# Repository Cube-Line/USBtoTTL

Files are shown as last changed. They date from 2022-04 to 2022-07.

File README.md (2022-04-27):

# USB转串口小工具硬件
发现大多数TB的USB串口工具老出各种意外,于是自己画了一版.
* 主控芯片使用CP2104,通讯速率最大可达2Mbps.
* 集成了功率开关-BD2243G-GTR(限流500mA)
* 集成电源和过功率指示灯、接收发送指示灯.
* USB口添加ESD保护-BDFN1710A054U.
* 添加3.3V线性稳压器，支持3V3逻辑电平.
* 添加DTR流控制，支持Arduino自动下载.

## 仿真图
* TOP  
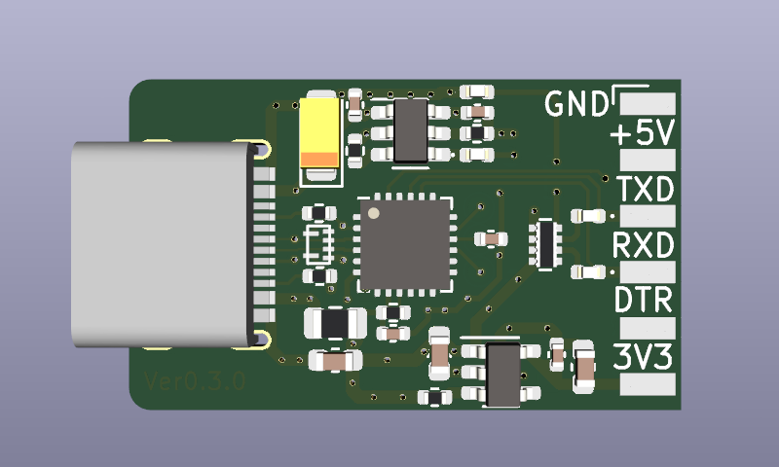
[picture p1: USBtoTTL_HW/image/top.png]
TOP
  
* BOTTOM  
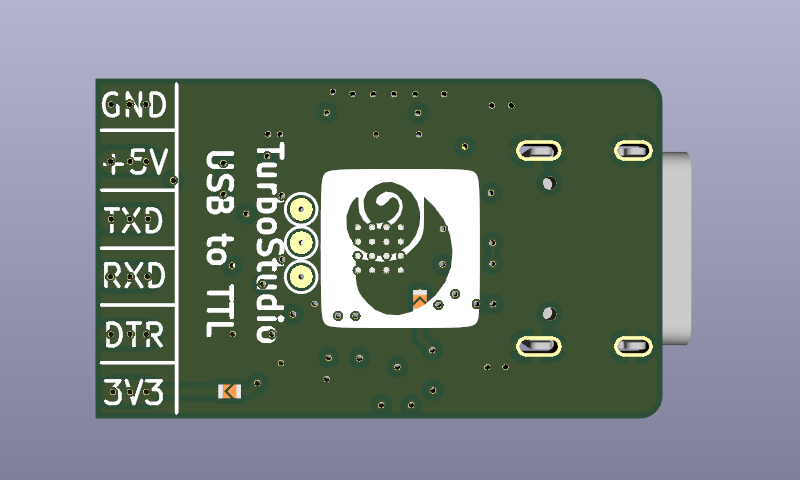
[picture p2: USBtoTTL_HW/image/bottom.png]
BOTTOM


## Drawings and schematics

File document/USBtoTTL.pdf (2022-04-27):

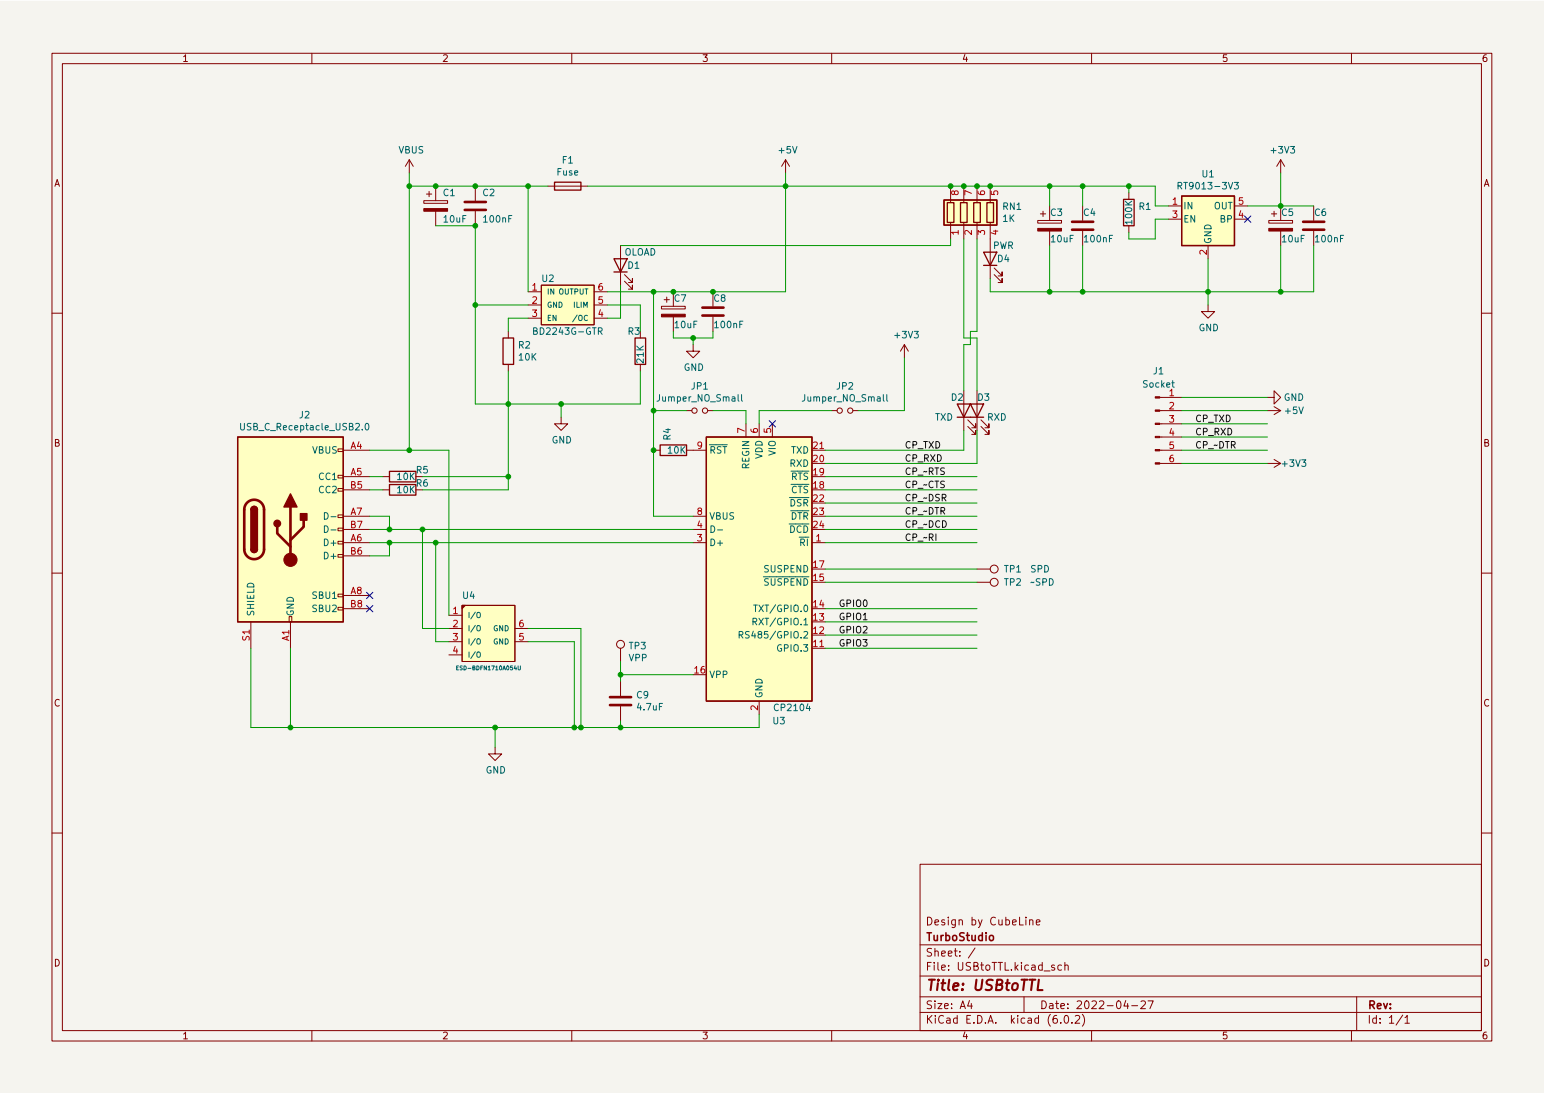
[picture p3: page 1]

2 RXD 20 TXD 21 ~{DSR}22 ~{DTR}23 ~{DCD}24 D+ 3 D- 4 VIO

File: USBtoTTL.kicad_sch Sheet: / TurboStudio Design by CubeLine

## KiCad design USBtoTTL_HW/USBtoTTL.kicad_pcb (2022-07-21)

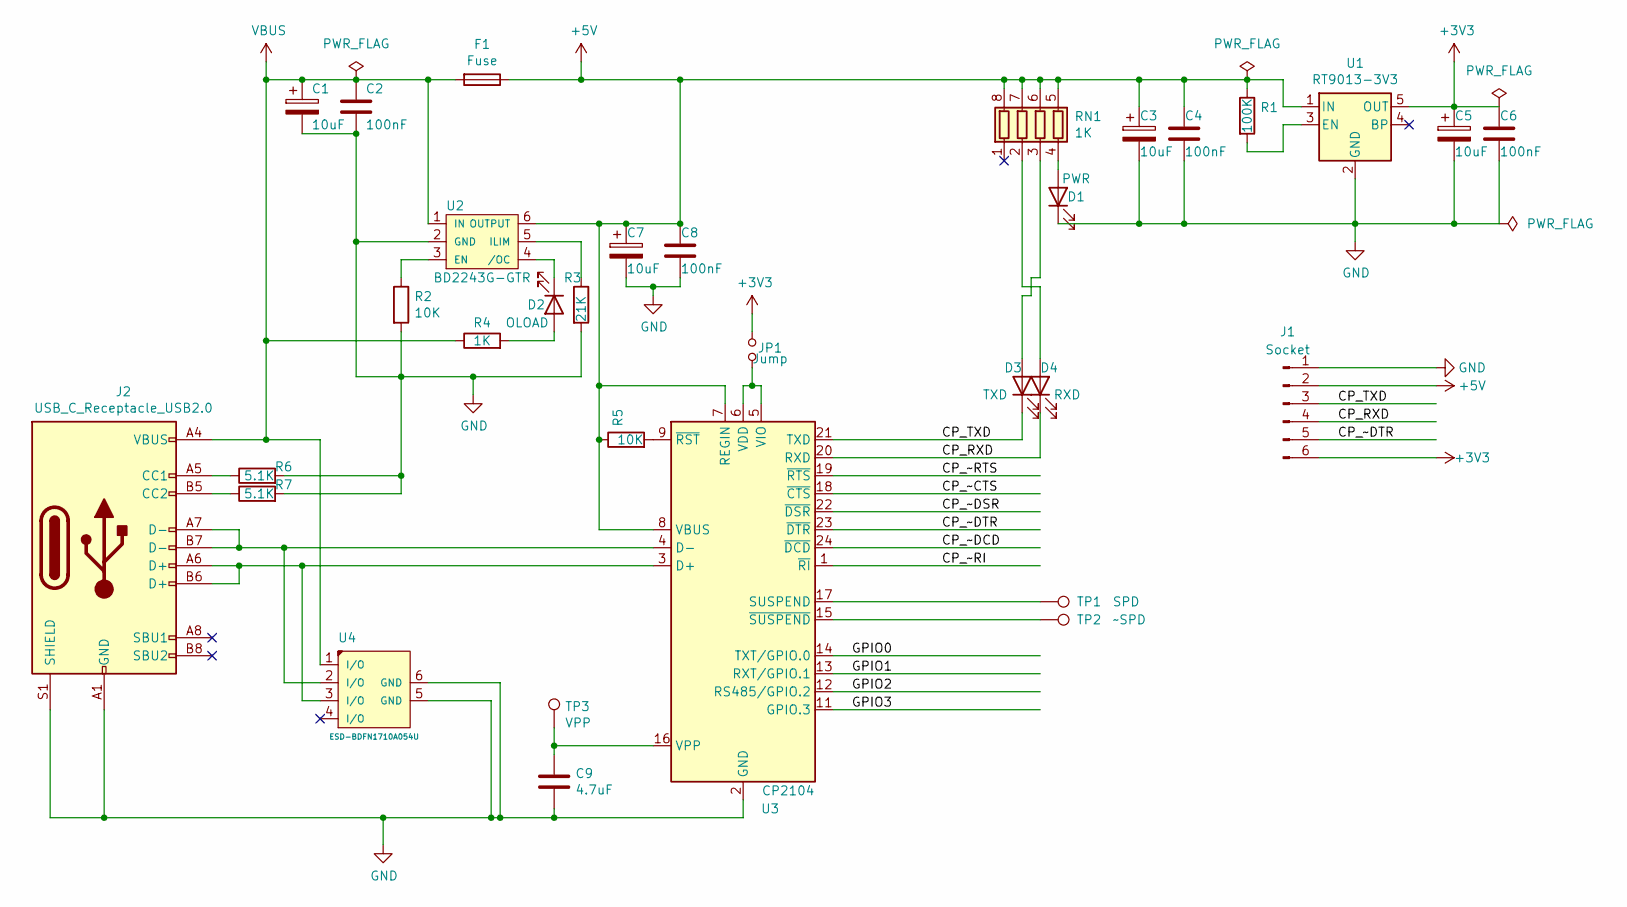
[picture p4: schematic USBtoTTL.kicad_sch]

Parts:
C1: 10uF; CP_EIA-3216-10_Kemet-I
C2, C4, C6, C8: 100nF; C_0402_1005Metric
C3, C5, C7: 10uF; C_0603_1608Metric
C9: 4.7uF; C_0402_1005Metric
D1: PWR; LED_0402_1005Metric
D2: OLOAD; LED_0402_1005Metric
D3: TXD; LED_0402_1005Metric
D4: RXD; LED_0402_1005Metric
F1: Fuse; Fuse_0805_2012Metric
J1: Socket; Harwin_M20-89006xx_1x06_P2.54mm_Horizontal
J2: USB_C_Receptacle_USB2.0; USB_C_Receptacle_HRO_TYPE-C-31-M-12
JP1: Jump; JUMP_OPEN_2P_0.3MMx0.5MM
R1: 100K; R_0402_1005Metric
R2, R5: 10K; R_0402_1005Metric
R3: 21K; R_0402_1005Metric
R4: 1K; R_0402_1005Metric
R6, R7: 5.1K; R_0402_1005Metric
RN1: 1K; R_Array_Concave_4x0402
TP1: SPD; TestPoint_Pad_D1.0mm
TP2: ~SPD; TestPoint_Pad_D1.0mm
TP3: VPP; TestPoint_Pad_D1.0mm
U1: RT9013-3V3; SOT-23-5
U2: BD2243G-GTR; SOT-23-6
U3: CP2104; QFN-24-1EP_4x4mm_P0.5mm_EP2.6x2.6mm
U4: ESD-BDFN1710A054U; DFN1710-6

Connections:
+3V3: C5.1, C6.1, J1.6, JP1.2, U1.5 (OUT)
+5V: C3.1, C4.1, C7.1, C8.1, F1.1, J1.2, R1.1, R5.1, RN1.5 (R4.2), RN1.6 (R3.2), RN1.7 (R2.2), RN1.8 (R1.2), U1.1 (IN), U2.6 (OUTPUT), U3.7 (REGIN), U3.8 (VBUS)
/CP_RXD: D4.1 (K), J1.4, U3.20 (RXD)
/CP_TXD: D3.1 (K), J1.3, U3.21 (TXD)
/CP_~CTS: U3.18 (~CTS)
/CP_~DCD: U3.24 (~DCD)
/CP_~DSR: U3.22 (~DSR)
/CP_~DTR: J1.5, U3.23 (~DTR)
/CP_~RI: U3.1 (~RI)
/CP_~RTS: U3.19 (~RTS)
/GPIO0: U3.14 (TXT/GPIO.0)
/GPIO1: U3.13 (RXT/GPIO.1)
/GPIO2: U3.12 (RS485/GPIO.2)
/GPIO3: U3.11 (GPIO.3)
GND: C1.2, C2.2, C3.2, C4.2, C5.2, C6.2, C7.2, C8.2, C9.2, D1.1 (K), J1.1, J2.A1 (GND), J2.A12 (GND), J2.B1 (GND), J2.B12 (GND), J2.S1 (SHIELD), R2.2, R3.2, R6.2, R7.2, U1.2 (GND), U2.2 (GND), U3.2 (GND), U3.25 (GND), U4.5 (GND), U4.6 (GND)
unnamed: C9.1, TP3.1, U3.16 (VPP)
unnamed: D1.2 (A), RN1.4 (R4.1)
unnamed: D2.1 (K), U2.4 (/OC)
unnamed: D2.2 (A), R4.2
unnamed: D3.2 (A), RN1.3 (R3.1)
unnamed: D4.2 (A), RN1.2 (R2.1)
unnamed: J2.A5 (CC1), R6.1
unnamed: J2.A6 (D+), J2.B6 (D+), U3.3 (D+), U4.3 (I/O)
unnamed: J2.A7 (D-), J2.B7 (D-), U3.4 (D-), U4.2 (I/O)
unnamed: J2.B5 (CC2), R7.1
unnamed: JP1.1, U3.5 (VIO), U3.6 (VDD)
unnamed: R1.2, U1.3 (EN)
unnamed: R2.1, U2.3 (EN)
unnamed: R3.1, U2.5 (ILIM)
unnamed: R5.2, U3.9 (~RST)
unnamed: TP1.1, U3.17 (SUSPEND)
unnamed: TP2.1, U3.15 (~SUSPEND)
VBUS: C1.1, C2.1, F1.2, J2.A4 (VBUS), J2.A9 (VBUS), J2.B4 (VBUS), J2.B9 (VBUS), R4.1, U2.1 (IN), U4.1 (I/O)

Board: 4 copper layers, 32 parts (4 on the bottom side), 24 nets, no tracks yet.

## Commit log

2022-04-27 首次提交
    [USBtoTTL-B_Cu.gbl, USBtoTTL-B_Mask.gbs, USBtoTTL-B_Paste.gbp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]
2022-04-27 更新README.md
    [USBtoTTL.kicad_sch]
2022-07-21 修复一些bug
    [USBtoTTL-B_Cu.gbl, USBtoTTL-B_Mask.gbs, USBtoTTL-B_Paste.gbp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]
